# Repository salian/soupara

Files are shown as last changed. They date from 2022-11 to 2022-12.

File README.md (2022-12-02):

# Soupara

A Budget 20-Key Macropad that uses tactile mechanical keys and is based on the Raspberry Pi Pico.



## Introduction

Macropads are small secondary keyboards that enable power users to boost their workflows for trading, programming, content creation, streaming, and even gaming with dedicated keys for keyboard shortcuts.

The objective of this project is to build a cheap but feature-rich and fully customizable macropad. 

A key project goal is to keep this extremely affordable as an entry-level macropad. The total cost including the PCB, Switches and Keycaps, a Pi Pico and the case should be under ₹1500 or sub-$20, which comes to under $1 per key. On a per-key basis, this might be one of the cheapest macropads in the world.

## Features

### Basic features

- 20 Programmable Keys
- RGB Underglow
- Compact and Affordable

### Optional features 

- QMK Compatibility
- OLED I2C Display
- Buzzer
- Haptic Feedback

## Getting one

#### Pre-assembled Units
A few pre-assembled prototype units are available for review and purchase.

#### Component Kits
A few kits including PCB and components are available to buy. Basic soldering skills are needed; most components are through-hole however there is one single component (RGB LED) which needs SMD soldering. An [assembly guide](docs/ASSEMBLY.md) is available.

#### Open Source Hardware
You can build this using the PCB files and Schematics from the repository. The cases can also be downloaded from the [hardware/case folder](hardware/rev%201/case/fdm-printable) for 3D-printing.

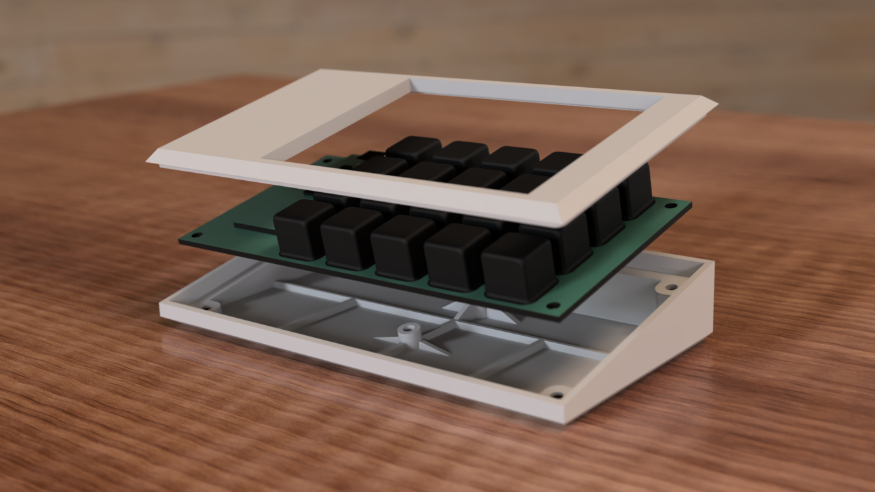
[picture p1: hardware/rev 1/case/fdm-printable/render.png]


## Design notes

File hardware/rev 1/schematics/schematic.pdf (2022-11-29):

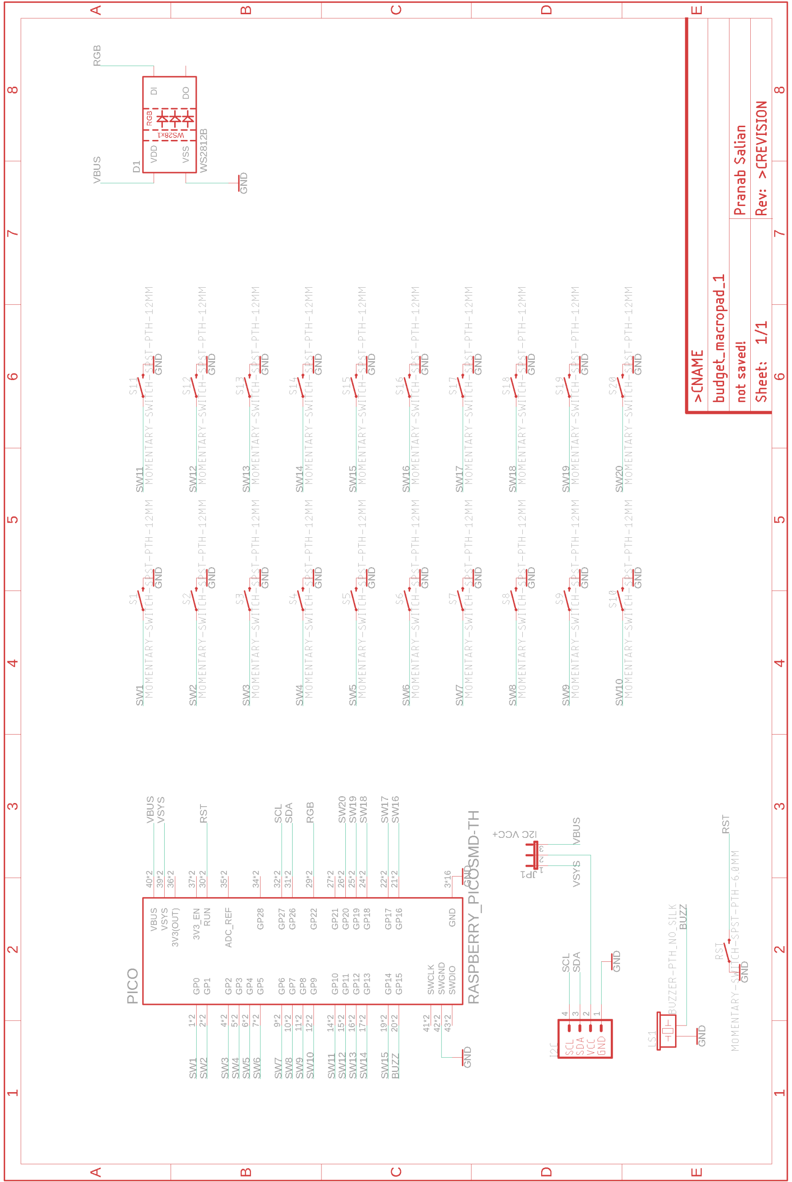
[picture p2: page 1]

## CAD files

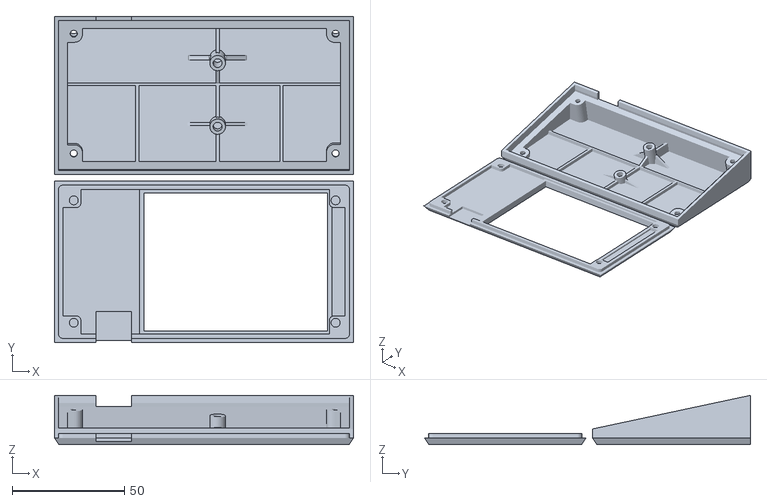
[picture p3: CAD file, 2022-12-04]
hardware/rev 1/case/fdm-printable/base_and_faceplate_v22.stl
133.5 x 145.5 x 22.0

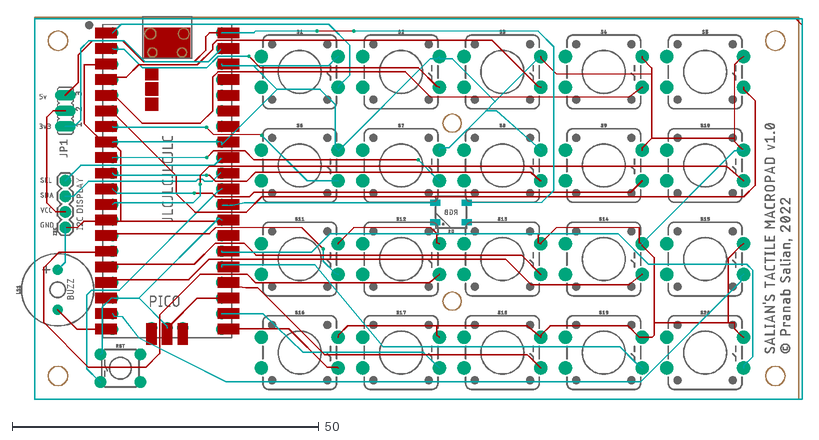
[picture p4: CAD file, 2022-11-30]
hardware/rev 1/pcb/pcb.dxf
128.0 x 62.5

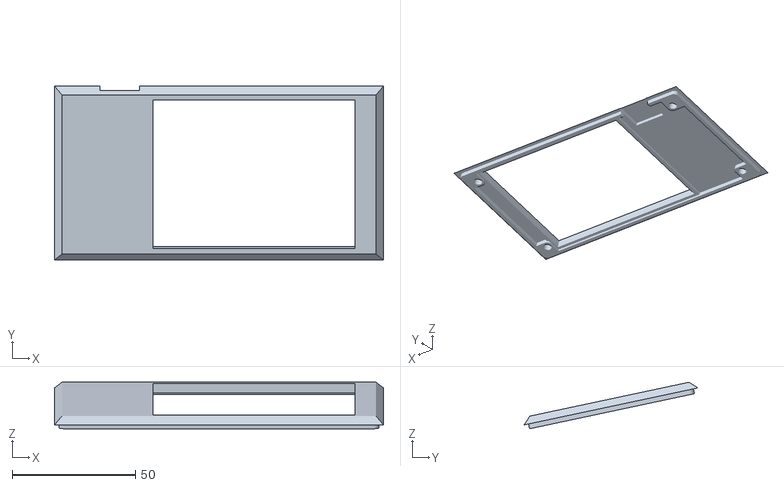
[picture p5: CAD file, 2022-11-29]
hardware/rev 1/case/fdm-printable/faceplate.stl
133.5 x 70.5 x 18.9

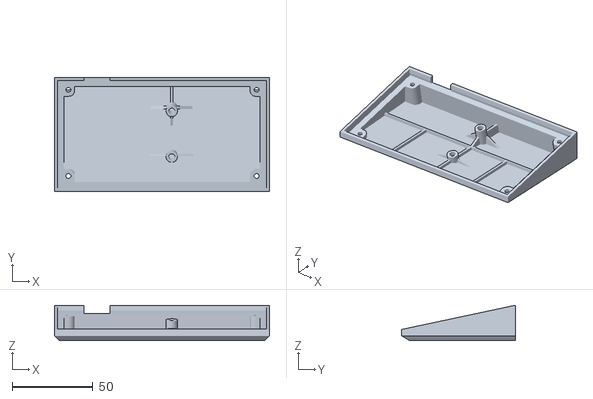
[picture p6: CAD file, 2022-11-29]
hardware/rev 1/case/fdm-printable/base.stl
133.5 x 70.5 x 22.0

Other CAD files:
hardware/rev 1/pcb/soupara-PCB-model.f3d

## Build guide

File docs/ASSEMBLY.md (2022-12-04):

# PCB Assembly

## BOM

To build the macropad you need 

| **Component** | **Qty** | **Price ₹** |
| :--- |:---:|:---|
| Raspberry Pi Pico | 1 | 320/- |
| 12x12x7.3mm Tactile Push Button Switch | 20 | 120/- |
| Keycaps (round or square for tactile switches) | 20 | 80/- |

Note: Avoid Omron Tactile Switches which have little nubs on the underside.

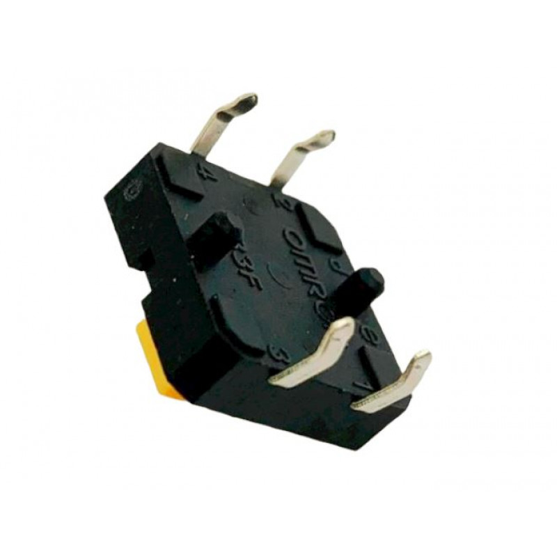
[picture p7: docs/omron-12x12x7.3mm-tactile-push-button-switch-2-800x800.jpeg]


Optionally you could also add

| **Optional Addons** | | |
| :--- |:---:|:---|
| Buzzer | 1 | 10/- |
| I2C display | 1 | 250/- |
| 1.27mm 1×40 Pin Male Single Row Header Strip | 1 | 20/- |
| Shorting Jumper | 1 | 2/- |
| WS2812B 5050 Addressable RGB LED | 1 | 5/- |

## Equipment

- Soldering Iron with fine tip
- Flux

## Assembly

#### Step I (optional)
- Start with soldering the (optional) WS2812B 5050 Addressable RGB LED on the underside of the PCB. 

#### Step II
- Solder on the Raspberry Pi Pico.

#### Step III (optional, if you soldered the RGB LED) 

- Plug the Raspberrry Pi Pico into your PC.
- Save the [latest Circuitpython UF2](https://circuitpython.org/board/raspberry_pi_pico/) file to the Pico.
- Upload the test [code.py](../firmware/circuitpython/rgb-led-test) to check if your LED was soldered on properly. The LED will cycle through various colours.

#### Step IV

- Solder the switches.
- Optionally break off a header strip into a 3-pin and 4-pin piece, and solder them into the jumper and I2C display holes on the PCB. This is needed only if you want to add in I2C peripherals. 

#### Step V

- Plug the Raspberrry Pi Pico into your PC
- Upload the sample [code.py](../firmware/circuitpython/sample) to the Pico. 
- [Download](https://circuitpython.org/libraries) the adafruit_hid folder and neopixel.mpy, adafruit_pixelbuf.mpy and neopixel_spi.mpy libraries and save to /lib on the Pico
- Edit code.py using Thonny or an editor of your choice, to customize the keys' functionality.
- Follow the assembly instructions for the case of your choice.

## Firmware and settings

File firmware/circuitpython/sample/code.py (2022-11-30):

# SPDX-FileCopyrightText: 2022 Pranab Salian
# SPDX-License-Identifier: GPL-3.0-or-later
# Soupara Tactile Macropad

import time
import board
import neopixel
from digitalio import DigitalInOut, Direction, Pull
import usb_hid
from adafruit_hid.keyboard import Keyboard
from adafruit_hid.keycode import Keycode
from adafruit_hid.consumer_control import ConsumerControl
from adafruit_hid.consumer_control_code import ConsumerControlCode

print("---Soupara Tactile Macropad---")

led = DigitalInOut(board.LED)
led.direction = Direction.OUTPUT
led.value = True

RED = (255, 0, 0)
YELLOW = (255, 150, 0)
GREEN = (0, 255, 0)
CYAN = (0, 255, 255)
BLUE = (0, 0, 255)
PURPLE = (180, 0, 255)
WHITE = (255, 255, 255)

pixel_pin = board.GP22
num_pixels = 1

# Flash the LED once
with neopixel.NeoPixel(pixel_pin, num_pixels) as pixels:
    pixels.fill(GREEN)
    time.sleep(0.5)

# Set up the underlight
# Brightness can go from 0.1 to 1.0
pixels = neopixel.NeoPixel(pixel_pin, num_pixels, brightness=0.1, auto_write=False)
pixels.fill(PURPLE)
pixels.show()

kbd = Keyboard(usb_hid.devices)
cc = ConsumerControl(usb_hid.devices)

# list of pins for keypad (skipping GP15 as it used to be funky, using it for Buzzer output)
pins = (
    board.GP0,
    board.GP1,
    board.GP2,
    board.GP3,
    board.GP4,
    board.GP5,
    board.GP6,
    board.GP7,
    board.GP8,
    board.GP9,
    board.GP10,
    board.GP11,
    board.GP12,
    board.GP13,
    board.GP14,
    board.GP16,
    board.GP17,
    board.GP18,
    board.GP19,
    board.GP20,
)

# GPIO 15 is made available on the PCB as BUZZ (intended for a Buzzer)
# but can also be used for other ideas like haptic feedback.

# GPIO 26 & 27 are also made available as I2C pins on the PCB

MEDIA = 1
KEY = 2

keymap = {
    (0): (KEY, (Keycode.GUI, Keycode.C)), # Mac Copy
    (1): (KEY, (Keycode.GUI, Keycode.V)), # Mac Paste
    (2): (KEY, [Keycode.THREE]),
    (3): (KEY, [Keycode.FOUR]),
    (4): (KEY, [Keycode.FIVE]),
    
    (5): (MEDIA, ConsumerControlCode.VOLUME_DECREMENT),
    (6): (MEDIA, ConsumerControlCode.VOLUME_INCREMENT),
    (7): (KEY, [Keycode.R]),
    (8): (KEY, [Keycode.G]),
    (9): (KEY, [Keycode.B]),
    
    (10): (KEY, [Keycode.UP_ARROW]),
    (11): (KEY, [Keycode.X]),  # plus key
    (12): (KEY, [Keycode.Y]),
    (13): (KEY, [Keycode.Z]),
    (14): (KEY, [Keycode.I]),
    
    (15): (KEY, [Keycode.O]),
    (16): (KEY, [Keycode.LEFT_ARROW]),
    (17): (KEY, [Keycode.DOWN_ARROW]),
    (18): (KEY, [Keycode.RIGHT_ARROW]),
    (19): (KEY, [Keycode.ALT]),

}

switches = []
for i in range(len(pins)):
    switch = DigitalInOut(pins[i])
    switch.direction = Direction.INPUT
    switch.pull = Pull.UP
    switches.append(switch)


switch_state = [0, 0, 0, 0, 0, 0, 0, 0, 0, 0, 0, 0, 0, 0, 0, 0, 0, 0, 0, 0]

while True:
    for button in range(20):
        if switch_state[button] == 0:
            if not switches[button].value:
                try:
                    if keymap[button][0] == KEY:
                        # This is a Key
                        kbd.press(*keymap[button][1])
                    else:
                        # This is a Media button
                        cc.send(keymap[button][1])
                except ValueError:  # deals with six key limit
                    pass
                switch_state[button] = 1

        if switch_state[button] == 1:
            if switches[button].value:
                try:
                    if keymap[button][0] == KEY:
                        kbd.release(*keymap[button][1])

                except ValueError:
                    pass
                switch_state[button] = 0

    time.sleep(0.01)  # debounce

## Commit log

2022-11-29 Add gerbers and other fabrication files
2022-11-30 PCB exported from Eagle
    [soupara-PCB-model.f3d]
2022-11-30 Add PCB DXF file
    [pcb.dxf]
2022-11-30 Add render of 3D-printable case
2022-11-30 Assembly Instructions
2022-11-30 Test RBG LED Soldering
2022-11-30 Add a circuitpython sample
2022-11-30 Bugfix Circuitpython Sample
2022-11-30 Add PCB Assembly Instructions
2022-11-30 Updated PCB Assembly instructions
2022-11-30 Added assembly guide
2022-11-30 Add a render of a case
2022-11-30 Add required CircuitPython libraries
2022-12-04 Add combined Base and Faceplate STL for 3D Print
    [base_and_faceplate_v22.stl]
2022-12-04 Add note about Omron switches
